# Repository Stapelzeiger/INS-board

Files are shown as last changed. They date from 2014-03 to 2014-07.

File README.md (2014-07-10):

INS-board
=========
This is a compact inertial navigation system (INS) board.
It is used as an autopilot for quad-copters and fixed wing aircrafts.

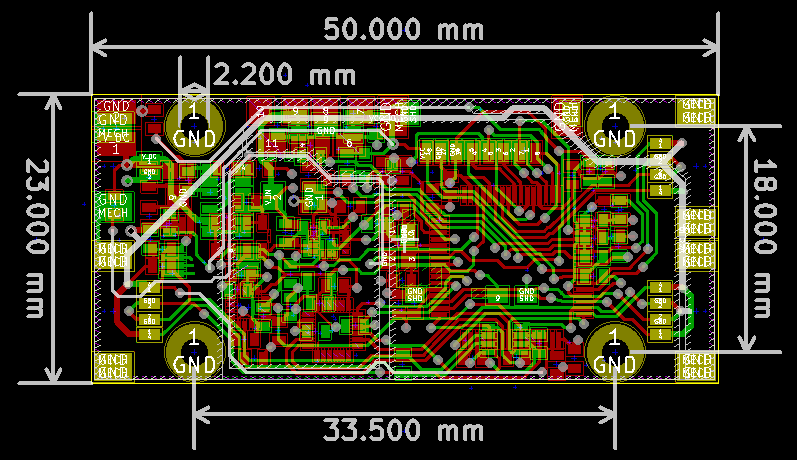
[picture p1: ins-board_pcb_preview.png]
Board Layout


Main features:
-------------
 - 3-axis gyroscope
 - Two 3-axis accelerometers (one for low g and one for high g accelerations)
 - 3-axis magnetometer
 - Barometer
 - ARM controller with FPU
 - microSD card
 - USB
 - 1x CAN
 - 4x UARTs
 - 1x I2C

Finished board
--------------

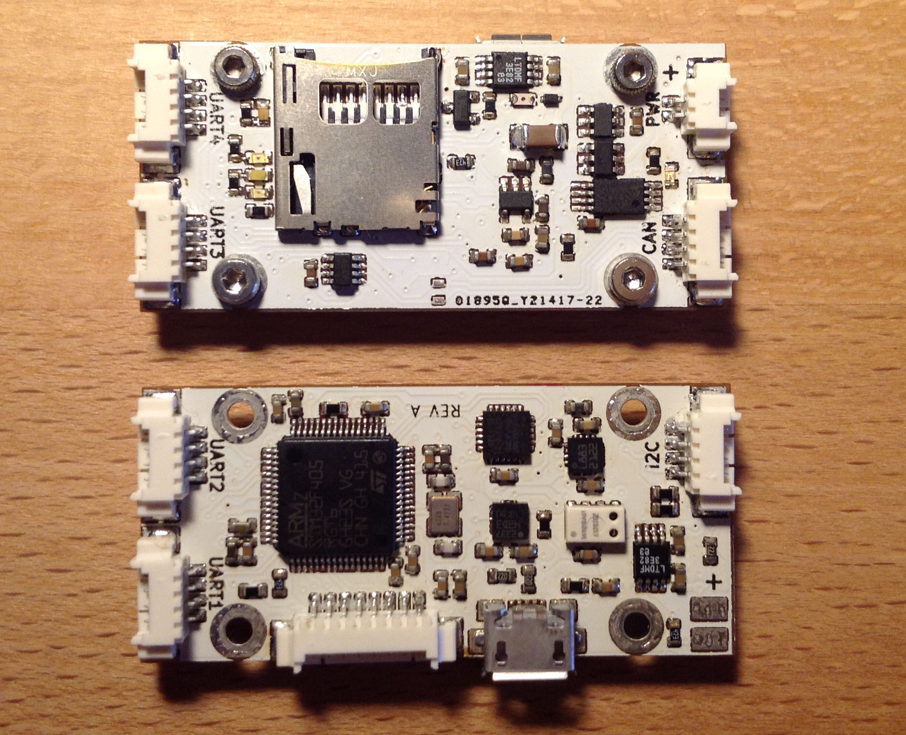
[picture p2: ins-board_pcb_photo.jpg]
Board Layout


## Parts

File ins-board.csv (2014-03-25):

Id | Designator | Package | Quantity | Designation | Supplier and ref
1 | C26 | SM1206 | 1 | 100uF
2 | X1 | _TSX-3225-SMD-XTAL | 1 | CRYSTAL 16MHz 10ppm
3 | U3 | _TSOT23-6 | 1 | LTC4412
4 | U6 | _TSOT23-5 | 1 | LT1761-3.3
5 | U4 | _SOT23-8 | 1 | MAX3051
6 | U5,U7 | _MSOP-8-EP | 2 | LT1965
7 | U8 | _MS5611-01BA | 1 | MS5611-01BA
8 | CONN3 | _Micro-USB-AB-receptacle-SMT | 1 | MICRO_USB
9 | U2 | _LQFP64 | 1 | STM32F415RGT6
10 | U10 | _HMC5883L | 1 | HMC5883L
11 | U11 | _H3LIS331DL | 1 | H3LIS331DL
12 | Q2 | _FAIRCHILD-MOSFET-SuperSOT-6 | 1 | FDC638APZ
13 | Q1 | _FAIRCHILD-MOSFET-SuperSOT-3 | 1 | FDN306P
14 | _M2,_M2,_M2,_M2 | _M2 | 4 | VAL**
15 | C6,C13,C9,C14,C10,C8,C7,C3,C28,C34,C32,C33,C29,C30,C19,C4,C17 | _0603-W | 17 | 0.1uF
16 | R21,R20,R14 | _0603-W | 3 | 47k
17 | C11,C12 | _0603-W | 2 | 2.2uF
18 | R8,R9,R7,R1,R6 | _0603-W | 5 | 1k
19 | R5,R2 | _0603-W | 2 | 10k
20 | R17,R16,R10,R11 | _0603-W | 4 | 4.7k
21 | C5,C2,C21,C27 | _0603-W | 4 | 1uF
22 | C1,C37,C18,C22,C25,C20,C23 | _0603-W | 7 | 10uF
23 | C36 | _0603-W | 1 | 4.7uF
24 | C35 | _0603-W | 1 | 0.22uF
25 | C31 | _0603-W | 1 | 2.2nF 50V
26 | R18 | _0603-W | 1 | NP / 120
27 | R12,R13 | _0603-W | 2 | 22
28 | F1 | _0603-W | 1 | FUSE 500mA
29 | R15 | _0603-W | 1 | 0
30 | R4,R3 | _0603-W | 2 | R
31 | FB1 | _0603-W | 1 | BLM18KG601SN1
32 | C24 | _0603-W | 1 | 0.01uF
33 | C15,C16 | _0603-W | 2 | 10pF
34 | D4 | _0603-W | 1 | STATUS
35 | D1 | _0603-W | 1 | SD ACT
36 | D5 | _0603-W | 1 | HEARTBEAT
37 | D3 | _0603-W | 1 | ERROR
38 | D2 | _0603-W | 1 | POWER
39 | U9 | _MPU-60X0 | 1 | MPU6000
40 | CONN2 | _Molex-microSD-502570-0893 | 1 | MICRO_SD
41 | CONN4 | _Molex-PicoBlade-SMD-4 | 1 | I2C/UART
42 | CONN5 | _Molex-PicoBlade-SMD-4 | 1 | CAN
43 | CONN6,CONN8,CONN9,CONN7 | _Molex-PicoBlade-SMD-4 | 4 | UART
44 | CONN1 | _Molex-PicoBlade-SMD-8 | 1 | JTAG
45 | P1 | _Molex-PicoBlade-SMD-2 | 1 | PWR
46 | P2 | _Solder_Pad2.54_2 | 1 | Power (Solder Pad)
47 | D6 | _SC79 | 1 | BAS52-02V
48 | U1 | _TSSOP-8 | 1 | 24LC128

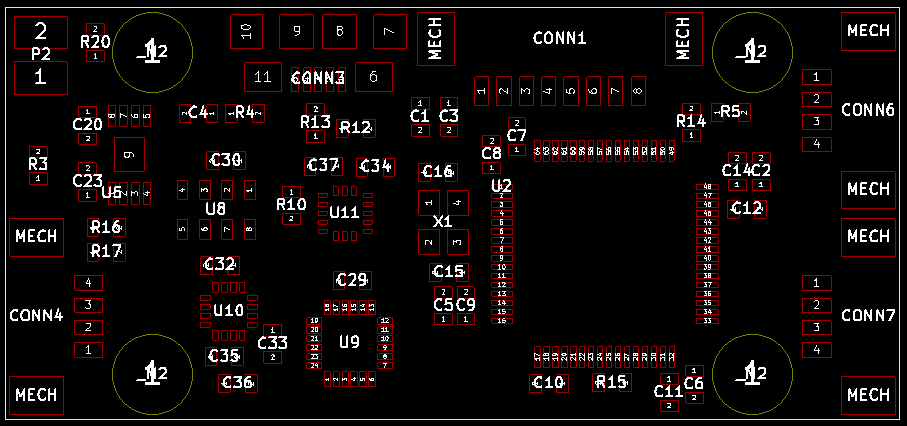
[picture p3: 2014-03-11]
ins-board-components.F.Cu.png

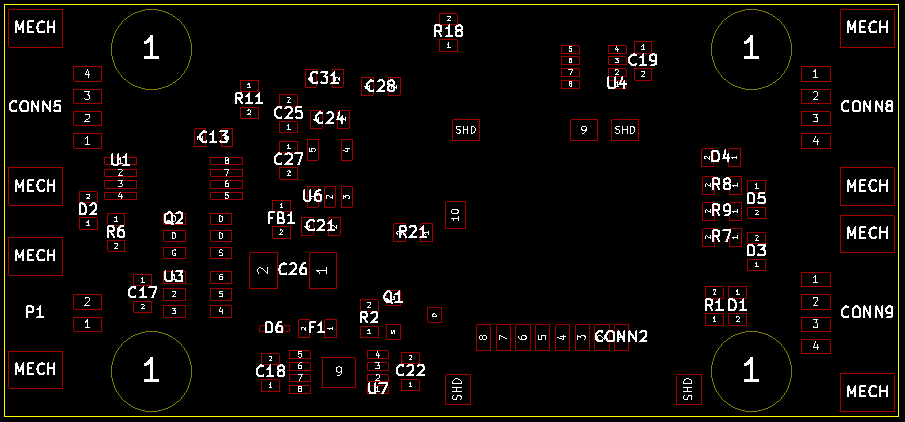
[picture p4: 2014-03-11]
ins-board-components.B.Cu.png

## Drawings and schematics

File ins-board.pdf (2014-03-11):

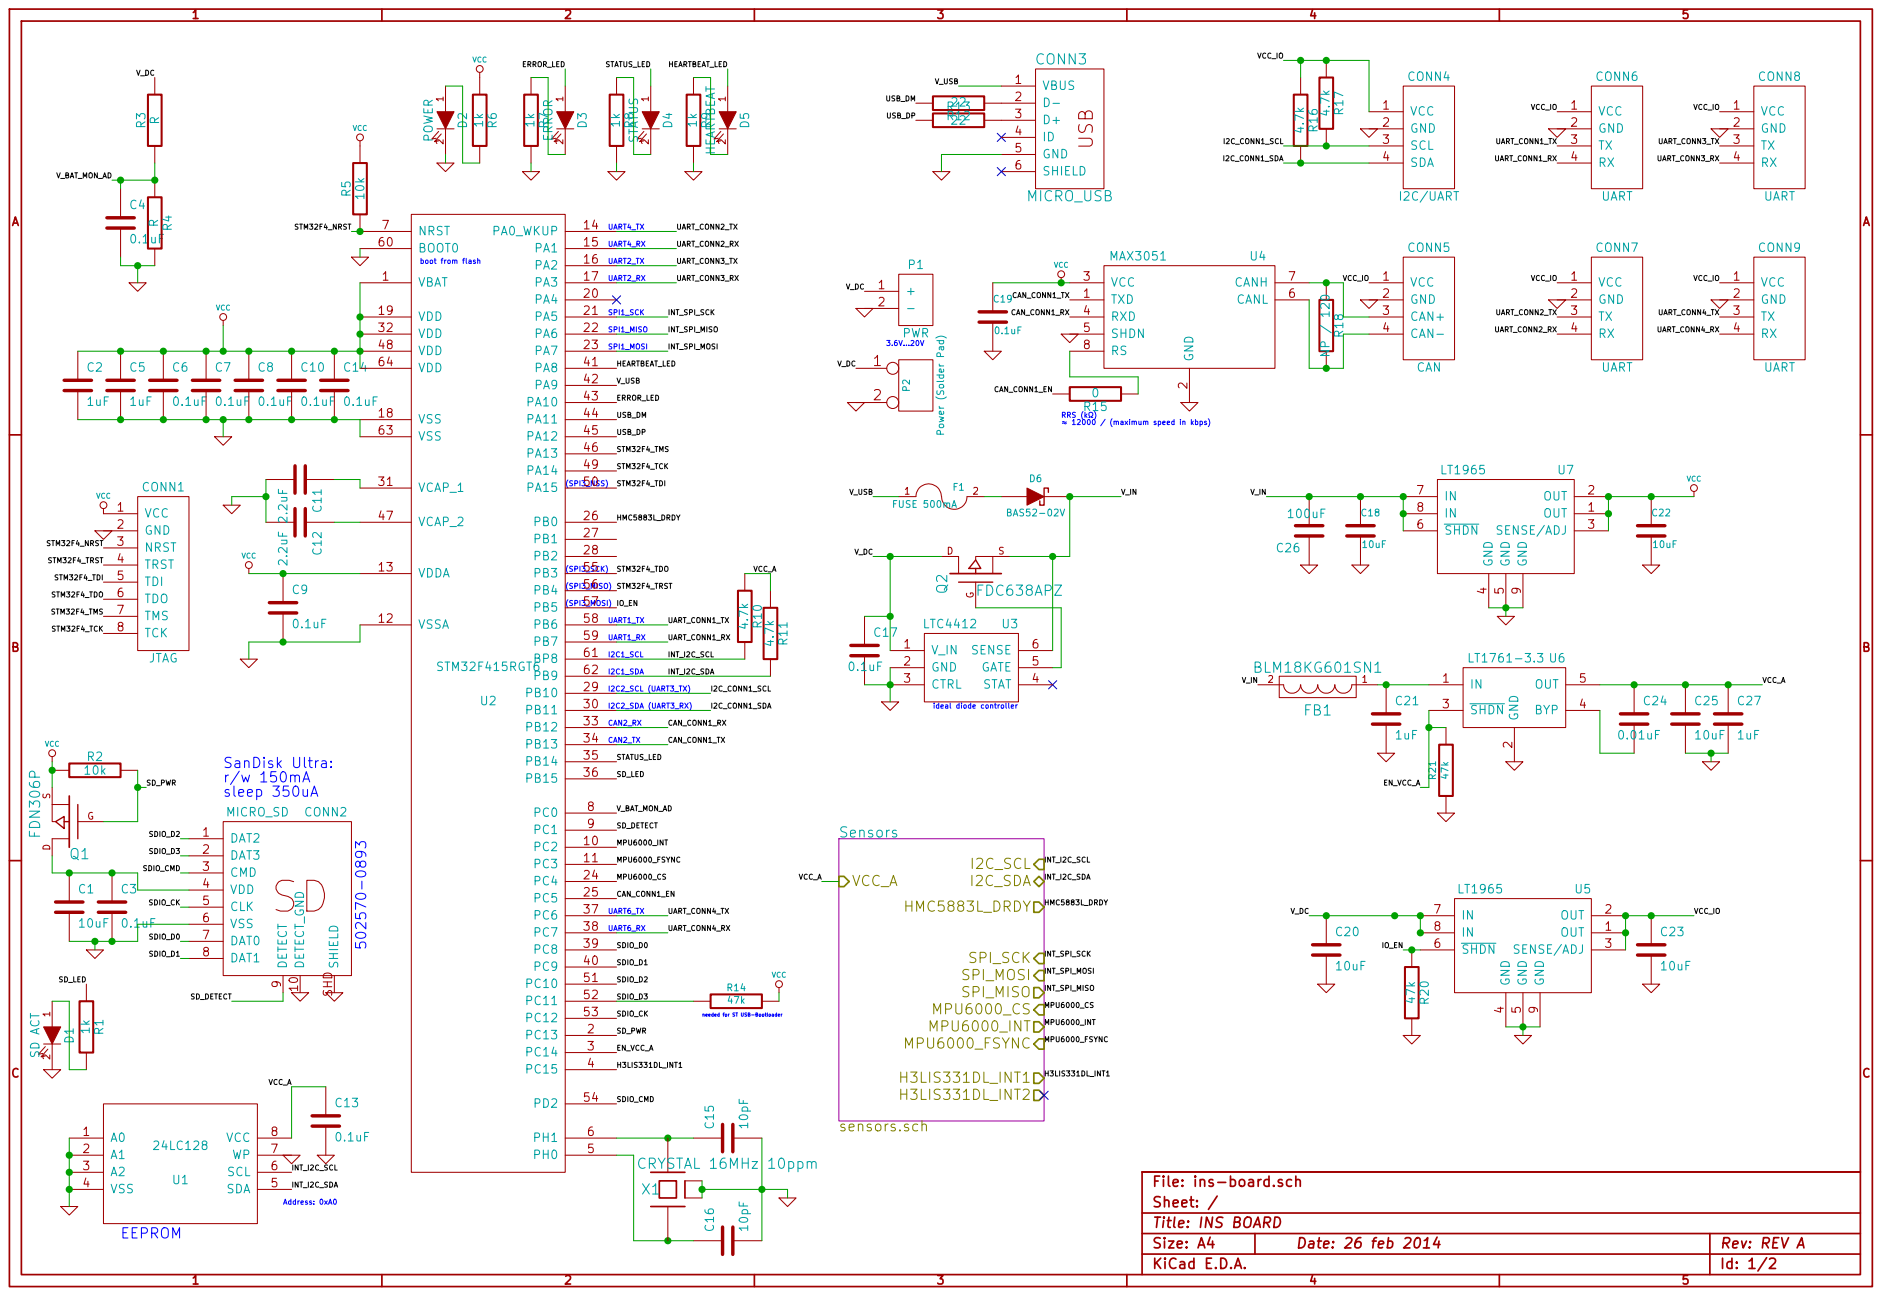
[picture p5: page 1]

boot from flash VCC R5 10k

2 VCC 3 RXD 4 SHDN 5 CANL 6 CANH 7 RS 8 MAX3051 U4

File: ins-board.sch Sheet: /

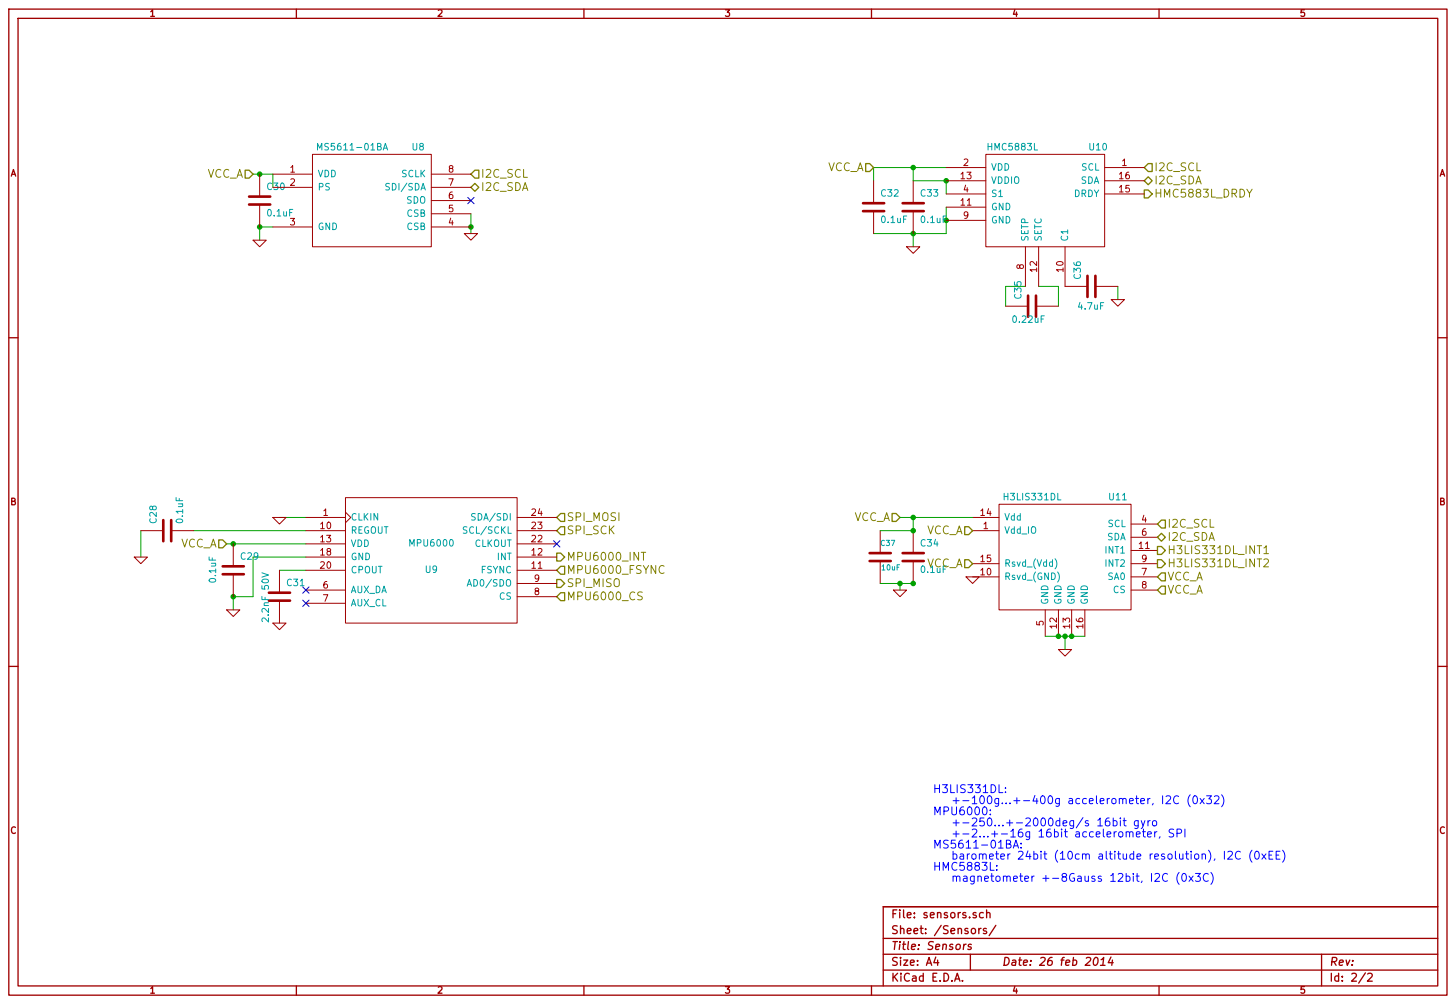
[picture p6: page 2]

8 GND 9 C1 10 GND 11 SETC 12 VDDIO 13 DRDY 15 SDA 16 HMC5883L U10 C33

Title: Sensors File: sensors.sch Sheet: /Sensors/

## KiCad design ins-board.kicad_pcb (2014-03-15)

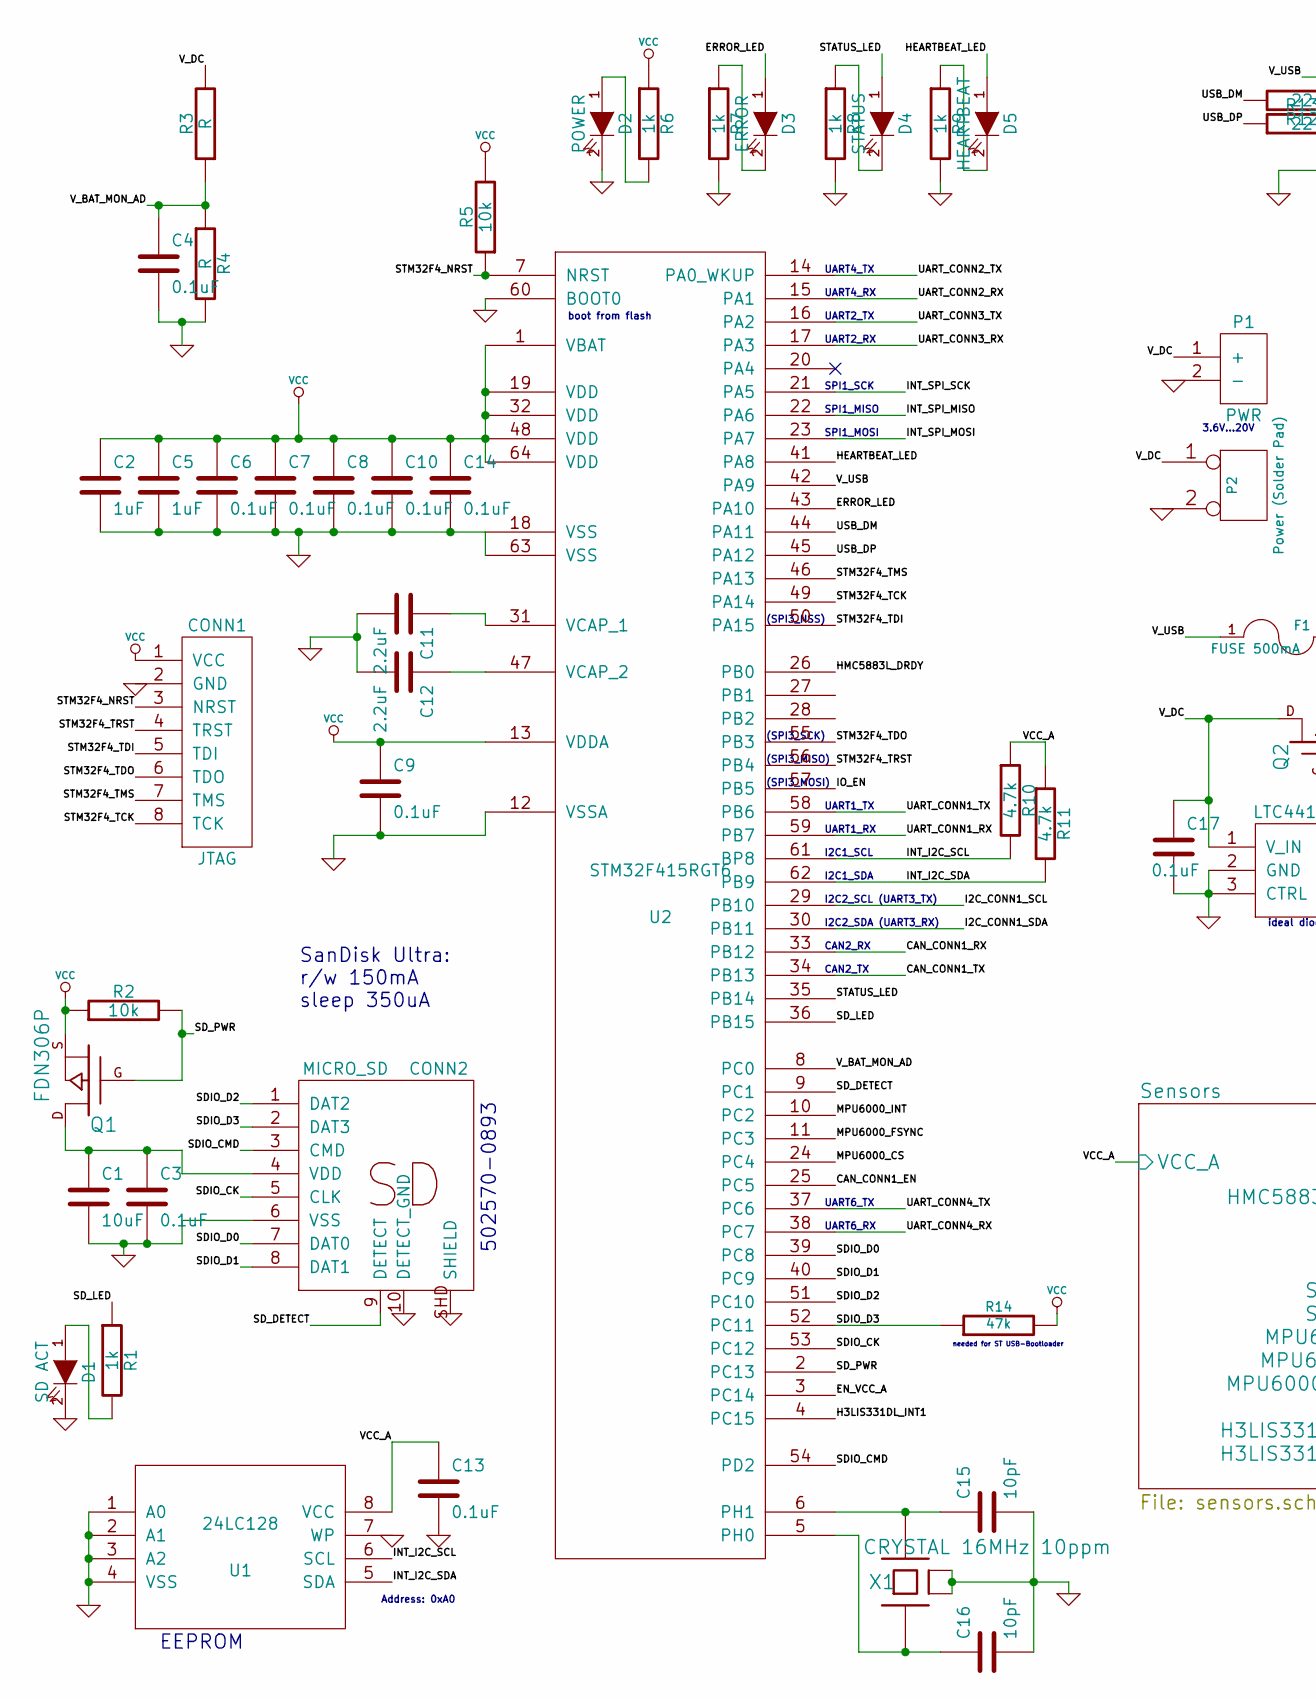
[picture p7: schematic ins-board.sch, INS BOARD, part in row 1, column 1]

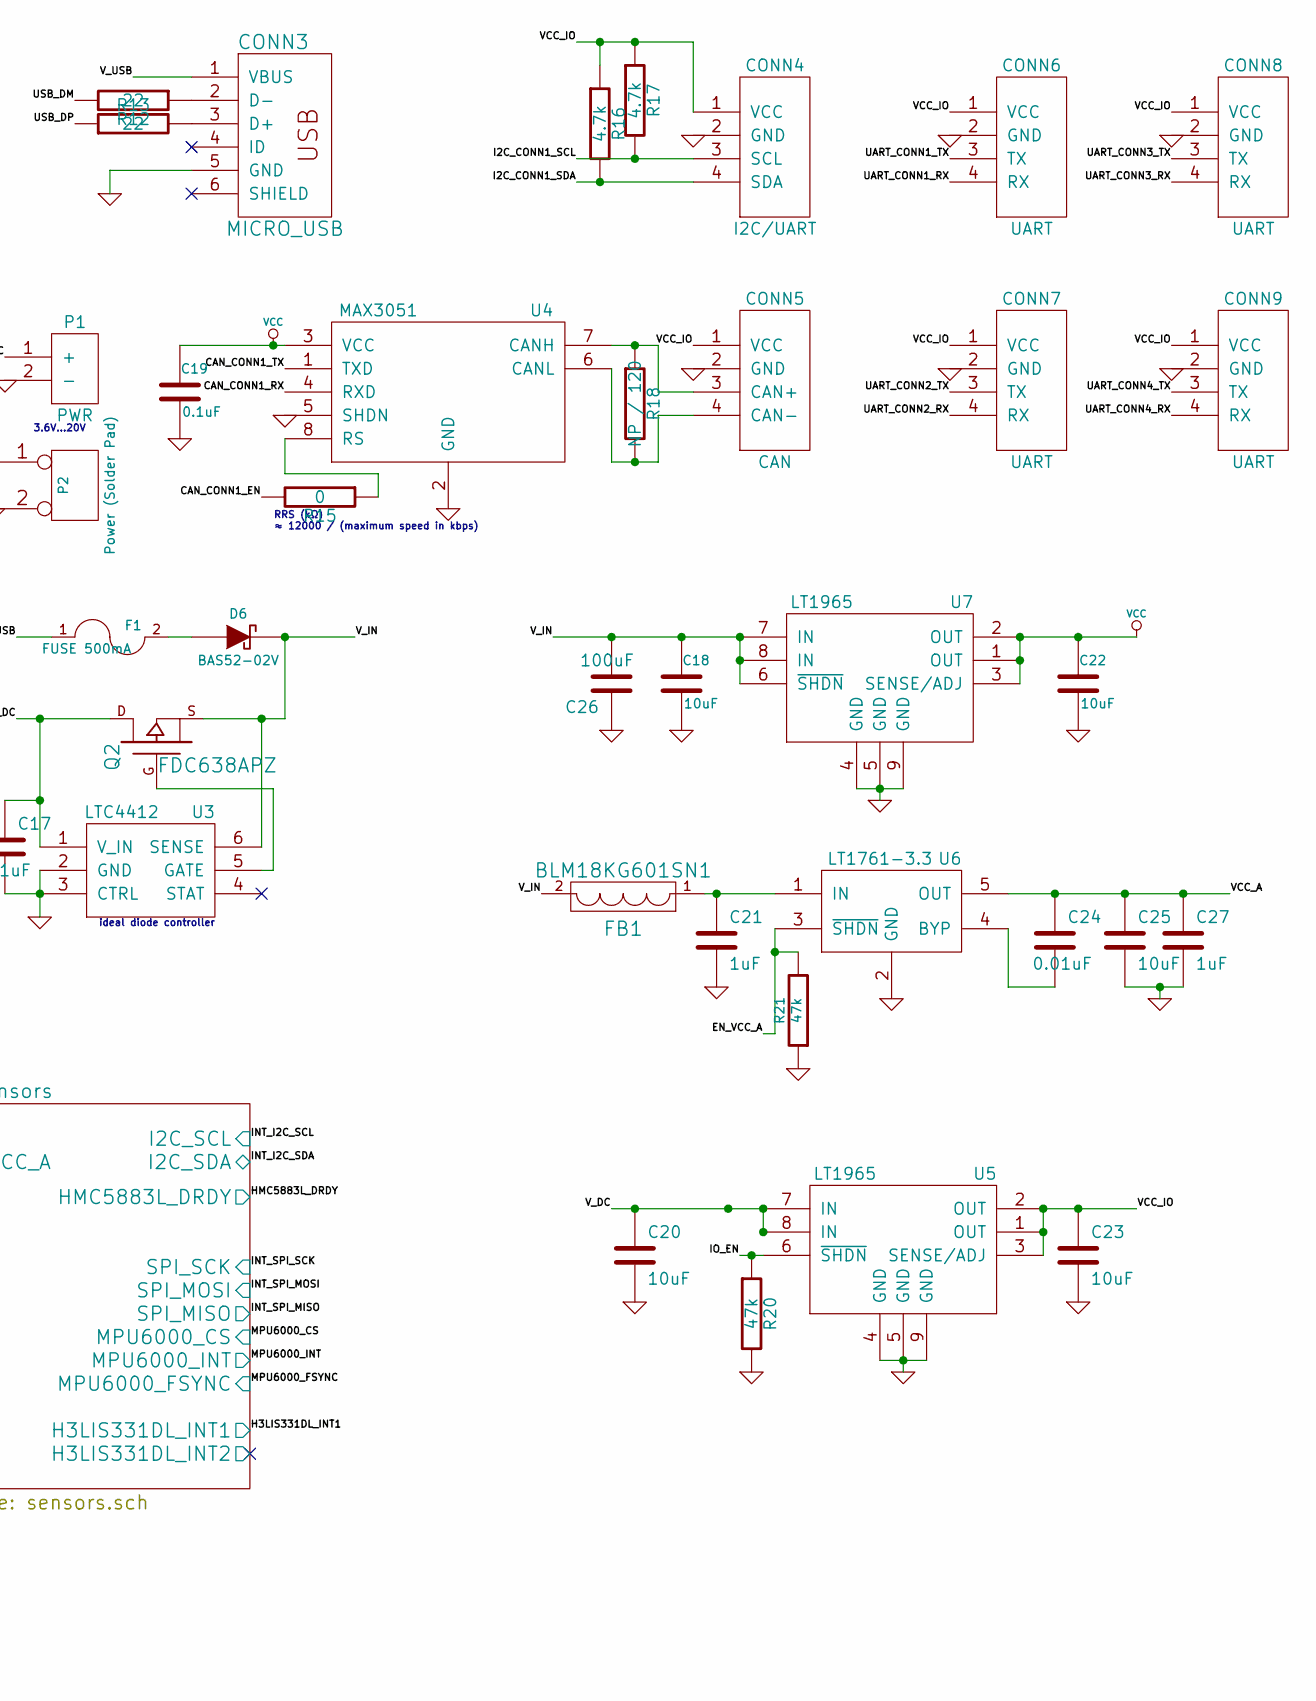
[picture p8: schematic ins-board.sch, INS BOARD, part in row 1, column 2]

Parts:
C1, C20, C23, C25: 10uF
C2, C5, C21, C27: 1uF
C3, C4, C6, C7, C8, C9, C10, C13, C14, C17: 0.1uF
C11, C12: 2.2uF
C15, C16: 10pF
C18, C22: 10uF
C19: 0.1uF
C24: 0.01uF
C26: 100uF; PartNum EMK325ABJ107MM-T
CONN1: JTAG; MODULE
CONN2: MICRO_SD; MODULE
CONN3: MICRO_USB
CONN4: I2C/UART; MODULE
CONN5: CAN; MODULE
CONN6, CONN7, CONN8, CONN9: UART; MODULE
D1: SD ACT
D2: POWER
D3: ERROR
D4: STATUS
D5: HEARTBEAT
D6: BAS52-02V
F1: FUSE 500mA
FB1: BLM18KG601SN1
P1: PWR; MODULE
P2: Power (Solder Pad)
Q1: FDN306P
Q2: FDC638APZ
R1, R6, R7, R8, R9: 1k
R2, R5: 10k
R3, R4: R
R10, R11, R16, R17: 4.7k
R12, R13: 22
R14, R21: 47k
R15: 0
R18: NP / 120
R20: 47k
U1: 24LC128; MODULE
U2: STM32F415RGT6; MODULE
U3: LTC4412; MODULE
U4: MAX3051; MODULE
U5, U7: LT1965; MODULE
U6: LT1761-3.3; MODULE
X1: CRYSTAL 16MHz 10ppm

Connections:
/CAN_CONN1_EN: R15.2, U2.25 (PC5)
/CAN_CONN1_RX: U2.33 (PB12), U4.4 (RXD)
/CAN_CONN1_TX: U2.34 (PB13), U4.1 (TXD)
/EN_VCC_A: R21.2, U2.3 (PC14), U6.3 (~SHDN)
/ERROR_LED: D3.1 (A), U2.43 (PA10)
/HEARTBEAT_LED: D5.1 (A), U2.41 (PA8)
/I2C_CONN1_SCL: CONN4.3 (SCL), R17.2, U2.29 (PB10)
/I2C_CONN1_SDA: CONN4.4 (SDA), R16.2, U2.30 (PB11)
/IO_EN: R20.1, U2.57 (PB5), U5.6 (~SHDN)
/SDIO_CK: CONN2.5 (CLK), U2.53 (PC12)
/SDIO_CMD: CONN2.3 (CMD), U2.54 (PD2)
/SDIO_D0: CONN2.7 (DAT0), U2.39 (PC8)
/SDIO_D1: CONN2.8 (DAT1), U2.40 (PC9)
/SDIO_D2: CONN2.1 (DAT2), U2.51 (PC10)
/SDIO_D3: CONN2.2 (DAT3), R14.1, U2.52 (PC11)
/SD_DETECT: CONN2.9 (DETECT), U2.9 (PC1)
/SD_LED: R1.1, U2.36 (PB15)
/SD_PWR: Q1.G, R2.2, U2.2 (PC13)
/STATUS_LED: D4.1 (A), U2.35 (PB14)
/STM32F4_NRST: CONN1.3 (NRST), R5.1, U2.7 (NRST)
/STM32F4_TCK: CONN1.8 (TCK), U2.49 (PA14)
/STM32F4_TDI: CONN1.5 (TDI), U2.50 (PA15)
/STM32F4_TDO: CONN1.6 (TDO), U2.55 (PB3)
/STM32F4_TMS: CONN1.7 (TMS), U2.46 (PA13)
/STM32F4_TRST: CONN1.4 (TRST), U2.56 (PB4)
/Sensors/H3LIS331DL_INT1: U2.4 (PC15); also elsewhere on the board
/Sensors/HMC5883L_DRDY: U2.26 (PB0); also elsewhere on the board
/Sensors/I2C_SCL: R10.2, U1.6 (SCL), U2.61 (BP8); also elsewhere on the board
/Sensors/I2C_SDA: R11.2, U1.5 (SDA), U2.62 (PB9); also elsewhere on the board
/Sensors/MPU6000_CS: U2.24 (PC4); also elsewhere on the board
/Sensors/MPU6000_FSYNC: U2.11 (PC3); also elsewhere on the board
/Sensors/MPU6000_INT: U2.10 (PC2); also elsewhere on the board
/Sensors/SPI_MISO: U2.22 (PA6); also elsewhere on the board
/Sensors/SPI_MOSI: U2.23 (PA7); also elsewhere on the board
/Sensors/SPI_SCK: U2.21 (PA5); also elsewhere on the board
/Sensors/VCC_A: C13.1, C24.1, C25.1, C27.1, R10.1, R11.1, U1.8 (VCC), U6.5 (OUT); also elsewhere on the board
/UART_CONN1_RX: CONN6.4 (RX), U2.59 (PB7)
/UART_CONN1_TX: CONN6.3 (TX), U2.58 (PB6)
/UART_CONN2_RX: CONN7.4 (RX), U2.15 (PA1)
/UART_CONN2_TX: CONN7.3 (TX), U2.14 (PA0_WKUP)
/UART_CONN3_RX: CONN8.4 (RX), U2.17 (PA3)
/UART_CONN3_TX: CONN8.3 (TX), U2.16 (PA2)
/UART_CONN4_RX: CONN9.4 (RX), U2.38 (PC7)
/UART_CONN4_TX: CONN9.3 (TX), U2.37 (PC6)
/USB_DM: R12.2, U2.44 (PA11)
/USB_DP: R13.1, U2.45 (PA12)
/VCC_IO: C23.1, CONN4.1 (VCC), CONN5.1 (VCC), CONN6.1 (VCC), CONN7.1 (VCC), CONN8.1 (VCC), CONN9.1 (VCC), R16.1, R17.1, U5.1 (OUT), U5.2 (OUT), U5.3 (SENSE/ADJ)
/V_BAT_MON_AD: C4.1, R3.1, R4.1, U2.8 (PC0)
/V_DC: C17.1, C20.1, P1.1 (+), P2.1, Q2.D, R3.2, U3.1 (V_IN), U5.7 (IN), U5.8 (IN)
/V_IN: C18.1, C26.2, D6.2 (K), FB1.2, Q2.S, U3.6 (SENSE), U7.6 (~SHDN), U7.7 (IN), U7.8 (IN)
/V_USB: CONN3.1 (VBUS), F1.1, U2.42 (PA9)
GND: C1.2, C2.2, C3.2, C4.2, C5.2, C6.2, C7.2, C8.2, C9.2, C10.2, C11.2, C12.2, C13.2, C14.2, C15.2, C16.2, C17.2, C18.2, C19.2, C20.2, C21.2, C22.2, C23.2, C25.2, C26.1, C27.2, CONN1.2 (GND), CONN1.MECH (GND), CONN2.6 (VSS), CONN2.10 (DETECT_GND), CONN2.SHD (SHIELD), CONN3.5 (GND), CONN4.2 (GND), CONN4.MECH (GND), CONN5.2 (GND), CONN5.MECH (GND), CONN6.2 (GND), CONN6.MECH (GND), CONN7.2 (GND), CONN7.MECH (GND), CONN8.2 (GND), CONN8.MECH (GND), CONN9.2 (GND), CONN9.MECH (GND), D1.2 (K), D2.2 (K), P1.2 (-), P1.MECH (GND), P2.2 (PM), R4.2, R7.2, R8.2, R9.2, R20.2, R21.1, U1.1 (A0), U1.2 (A1), U1.3 (A2), U1.4 (VSS), U1.7 (WP), U2.12 (VSSA), U2.18 (VSS), U2.60 (BOOT0), U2.63 (VSS), U3.2 (GND), U3.3 (CTRL), U4.2 (GND), U4.5 (SHDN), U5.4 (GND), U5.5 (GND), U5.9 (GND), U6.2 (GND), U7.4 (GND), U7.5 (GND), U7.9 (GND), X1.2 (case), X1.4 (case); also elsewhere on the board
unnamed: D6.1 (A), F1.2
unnamed: C24.2, U6.4 (BYP)
unnamed: R15.1, U4.8 (RS)
unnamed: C11.1, U2.31 (VCAP_1)
unnamed: C12.1, U2.47 (VCAP_2)
unnamed: D2.1 (A), R6.2
unnamed: D5.2 (K), R9.1
unnamed: D4.2 (K), R8.1
unnamed: CONN3.2 (D-), R12.1
unnamed: CONN3.3 (D+), R13.2
unnamed: C16.1, U2.5 (PH0), X1.1
unnamed: C15.1, U2.6 (PH1), X1.3
unnamed: D3.2 (K), R7.1
unnamed: Q2.G, U3.5 (GATE)
unnamed: D1.1 (A), R1.2
unnamed: C21.1, FB1.1, U6.1 (IN)
unnamed: CONN5.3 (CAN+), R18.1, U4.7 (CANH)
unnamed: CONN5.4 (CAN-), R18.2, U4.6 (CANL)
unnamed: C1.1, C3.1, CONN2.4 (VDD), Q1.D
VCC: C2.1, C5.1, C6.1, C7.1, C8.1, C9.1, C10.1, C14.1, C19.1, C22.1, CONN1.1 (VCC), Q1.S, R2.1, R5.2, R6.1, R14.2, U2.1 (VBAT), U2.13 (VDDA), U2.19 (VDD), U2.32 (VDD), U2.48 (VDD), U2.64 (VDD), U4.3 (VCC), U7.1 (OUT), U7.2 (OUT), U7.3 (SENSE/ADJ)

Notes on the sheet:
ideal diode controller
Address: 0xA0
SanDisk Ultra: r/w 150mA sleep 350uA
(SPI3_MOSI)
(SPI3_MISO)
(SPI3_SCK)
(SPI3_NSS)
CAN2_TX
CAN2_RX
I2C2_SDA (UART3_RX)
I2C2_SCL (UART3_TX)
I2C1_SDA
I2C1_SCL
UART1_TX
UART1_RX
SPI1_MOSI
SPI1_MISO
SPI1_SCK
UART2_RX
UART2_TX
UART4_RX
UART4_TX
UART6_RX
UART6_TX
3.6V...20V
boot from flash
502570-0893
RRS (kΩ) ≈ 12000 / (maximum speed in kbps)
EEPROM
needed for ST USB-Bootloader

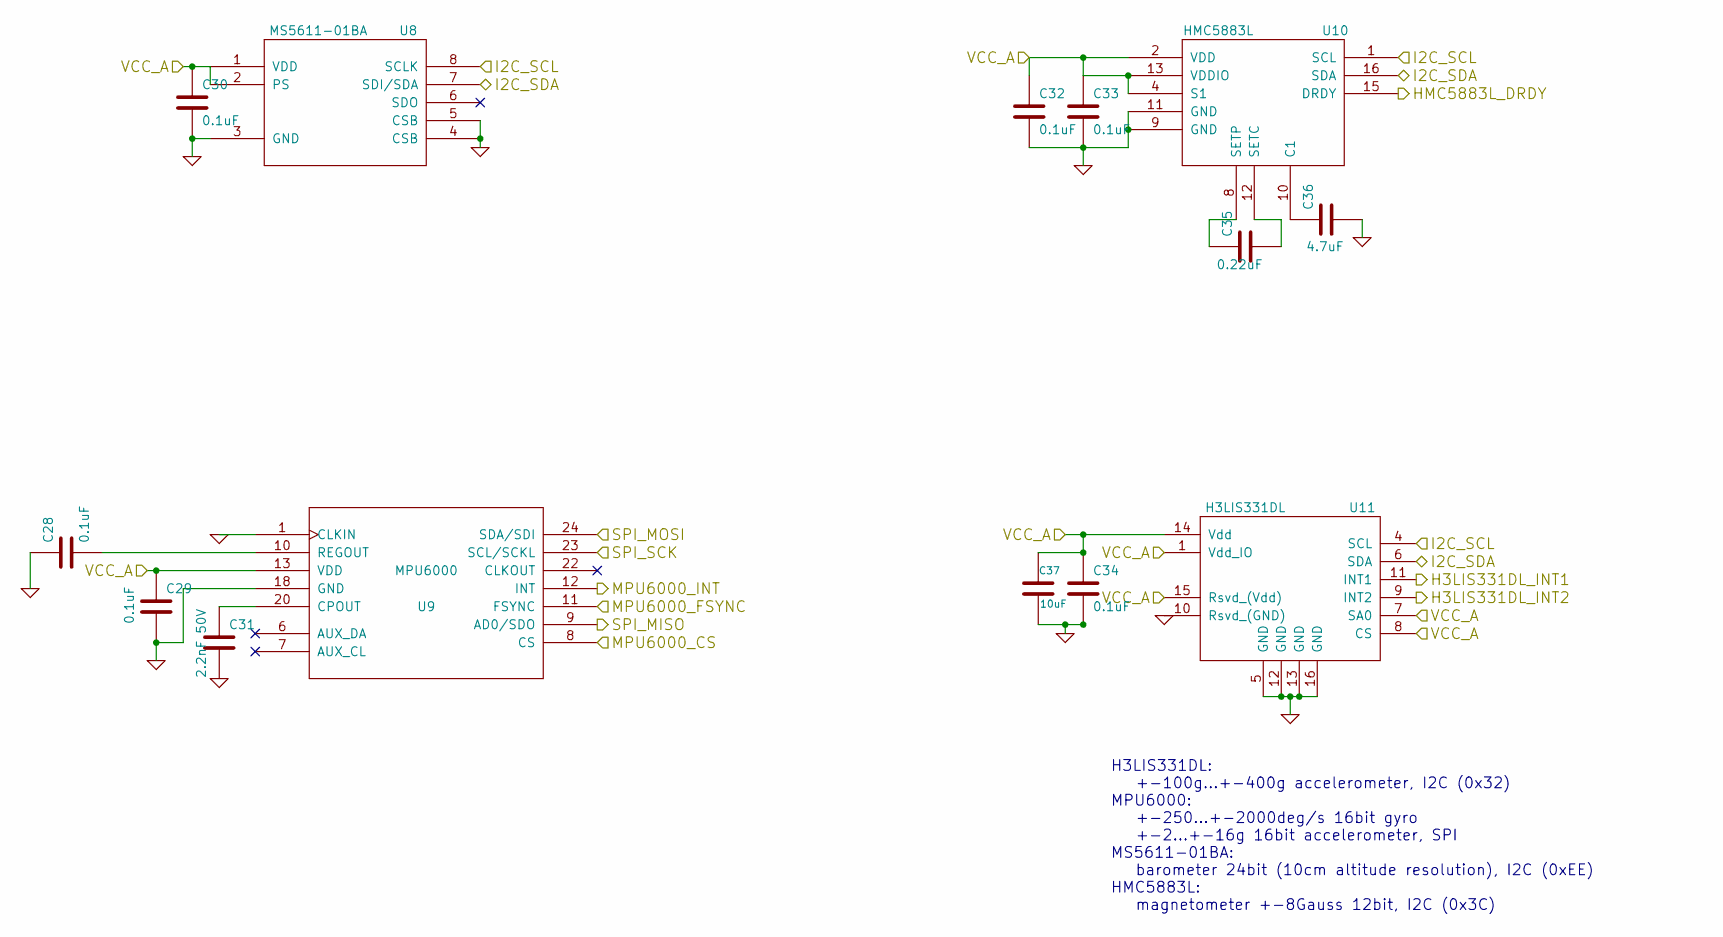
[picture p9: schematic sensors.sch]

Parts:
C28, C29, C30, C32, C33, C34: 0.1uF
C31: 2.2nF 50V
C35: 0.22uF
C36: 4.7uF
C37: 10uF
U8: MS5611-01BA; MODULE
U9: MPU6000; MODULE
U10: HMC5883L; MODULE
U11: H3LIS331DL; MODULE

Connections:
/Sensors/H3LIS331DL_INT1: U11.11 (INT1); also elsewhere on the board
/Sensors/HMC5883L_DRDY: U10.15 (DRDY); also elsewhere on the board
/Sensors/I2C_SCL: U8.8 (SCLK), U10.1 (SCL), U11.4 (SCL); also elsewhere on the board
/Sensors/I2C_SDA: U8.7 (SDI/SDA), U10.16 (SDA), U11.6 (SDA); also elsewhere on the board
/Sensors/MPU6000_CS: U9.8 (CS); also elsewhere on the board
/Sensors/MPU6000_FSYNC: U9.11 (FSYNC); also elsewhere on the board
/Sensors/MPU6000_INT: U9.12 (INT); also elsewhere on the board
/Sensors/SPI_MISO: U9.9 (AD0/SDO); also elsewhere on the board
/Sensors/SPI_MOSI: U9.24 (SDA/SDI); also elsewhere on the board
/Sensors/SPI_SCK: U9.23 (SCL/SCKL); also elsewhere on the board
/Sensors/VCC_A: C29.1, C30.1, C32.1, C33.1, C34.1, C37.1, U8.1 (VDD), U8.2 (PS), U9.13 (VDD), U10.2 (VDD), U10.4 (S1), U10.13 (VDDIO), U11.1 (Vdd_IO), U11.7 (SA0), U11.8 (CS), U11.14 (Vdd), U11.15 (Rsvd_(Vdd)); also elsewhere on the board
GND: C28.1, C29.2, C30.2, C31.2, C32.2, C33.2, C34.2, C36.2, C37.2, U8.3 (GND), U8.4 (CSB), U8.5 (CSB), U9.1 (CLKIN), U9.18 (GND), U10.9 (GND), U10.11 (GND), U11.5 (GND), U11.10 (Rsvd_(GND)), U11.12 (GND), U11.13 (GND), U11.16 (GND); also elsewhere on the board
unnamed: C35.1, U10.8 (SETP)
unnamed: C36.1, U10.10 (C1)
unnamed: C35.2, U10.12 (SETC)
unnamed: C31.1, U9.20 (CPOUT)
unnamed: C28.2, U9.10 (REGOUT)

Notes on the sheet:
H3LIS331DL: +-100g...+-400g accelerometer, I2C (0x32) MPU6000: +-250...+-2000deg/s 16bit gyro +-2...+-16g 16bit accelerometer, SPI MS5611-01BA: barometer 24bit (10cm altitude resolution), I2C (0xEE) HMC5883L: magnetometer +-8Gauss 12bit, I2C (0x3C)

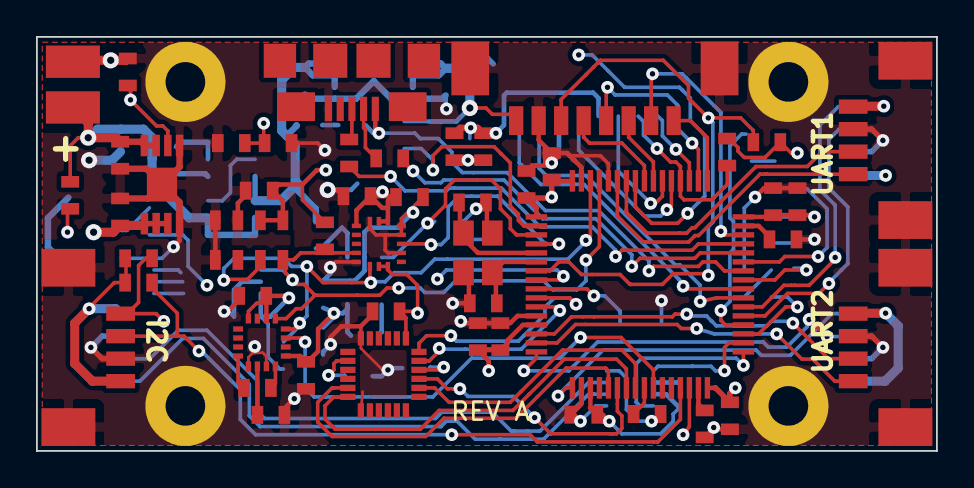
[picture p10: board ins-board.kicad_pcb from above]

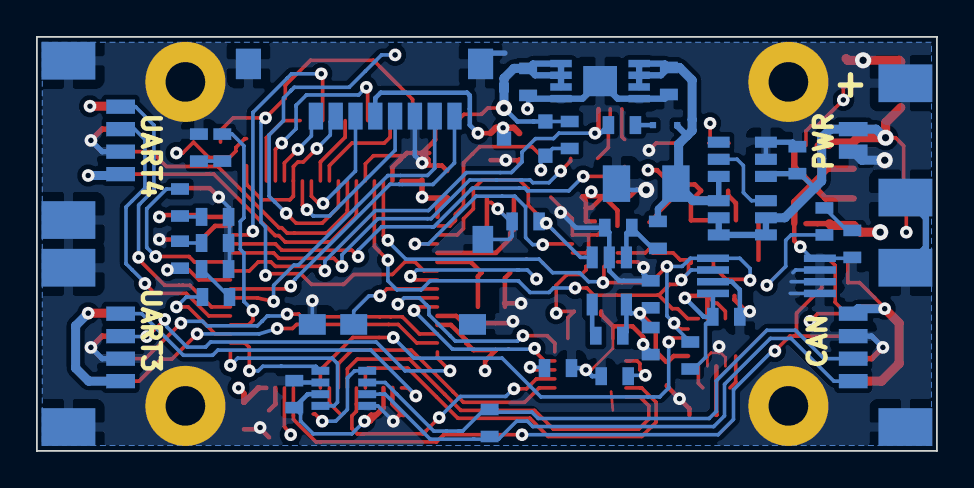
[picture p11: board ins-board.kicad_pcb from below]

Board: 4 copper layers, 50.0 x 23.0 mm, 94 parts (41 on the bottom side), 77 nets.

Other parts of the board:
_M2, _M2#2, _M2#3, _M2#4: VAL**; _M2

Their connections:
GND: _M2.1, _M2#2.1, _M2#3.1, _M2#4.1; also elsewhere on the board

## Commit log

2014-02-03 added a KiCad library submodule
2014-02-03 updated kicad-library
2014-02-03 updated kicad-lib
2014-02-03 add mosfet for current limiter
    [ins-board.sch]
2014-02-06 remove usb shield connection
    [ins-board.sch, sensors.sch]
2014-02-07 fix errors detected by ERC
    [ins-board.sch, sensors.sch]
2014-02-07 replaced crystal symbol
    [ins-board.sch, sensors.sch]
2014-02-07 assigned most footprints to symbols
    added missing footprint library references to project file.
2014-02-07 changed shunt resistor to 68mOhm, 0603
    [ins-board.sch, sensors.sch]
2014-02-07 switched to renamed component and footprint libraries
    [ins-board.sch, sensors.sch]
2014-02-09 new power design
    - separate voltage regulator for io-connectors (powered from DC-in only)
    - removed io hot-swap controller
    [ins-board.sch, sensors.sch]
2014-02-09 updated annotation, added MOSFET footprints
    [ins-board.sch, sensors.sch]
2014-02-10 updated crystal load capacitor values
    [ins-board.sch]
2014-02-11 updated some capacitor footprints
    [ins-board.sch, sensors.sch]
2014-02-11 added capacitor for max3051
    [ins-board.sch]
2014-02-13 changed sensors power supply (VCC_IO = VCC_A)
    - all sensors and the eeprom are now powered by VCC_A
    - internal I2C pullups to VCC_A
    Reason: MS5611-01BA, HMC5883L datasheets don't specify behaviour if only vcc_io is powered / if I2C is pulled to VCC while chip is powered down
    [ins-board.sch, sensors.sch]
2014-02-13 corrected connection error
    U5 pin 8,6 were connected
    [ins-board.sch]
2014-02-13 sort components
    [ins-board.kicad_pcb]
2014-02-13 change 24LC128 footprint from TSSOP to MSOP
    reason: smaller
    [ins-board.kicad_pcb]
2014-02-13 add m2 mounting holes
    [ins-board.kicad_pcb]
2014-02-14 changed SD card holder + some minor power supply changes
    [ins-board.sch, sensors.sch]
2014-02-14 layout
    90% of components
    [ins-board.kicad_pcb]
2014-02-15 add sd-card adapter, change 0603 footprints, design rules
    [ins-board.kicad_pcb]
2014-02-15 started routing
    [ins-board.kicad_pcb]
2014-02-16 updated library, changed component names according to new lib
    This fixes the library editor problem, where components disappear.
    [ins-board.sch, sensors.sch]
2014-02-16 modified sd card symbol to match footprint
    [ins-board.sch, sensors.sch]
2014-02-17 signal routing
    [ins-board.kicad_pcb]
2014-02-18 signal routing, all components placed
    [ins-board.kicad_pcb, ins-board.sch]
2014-02-18 solid copper connection for mounting holes
    [ins-board.kicad_pcb]
2014-02-19 power routing
    [ins-board.kicad_pcb]
2014-02-21 routing, added dimensions
    [ins-board.kicad_pcb]
2014-02-22 routing (io_en)
    [ins-board.kicad_pcb, ins-board.sch, sensors.sch]
2014-02-24 power supply solder pad connector
    [ins-board.kicad_pcb, ins-board.sch, sensors.sch]
2014-02-25 routing 100%
    [ins-board.kicad_pcb]
2014-02-25 optimize routing
    [ins-board.kicad_pcb]
2014-02-25 small fix, passes drc (except pad-to-pad distance for footprints)
    [ins-board.kicad_pcb]
2014-02-25 connect molex mechanical connector pads to GND
    [ins-board.kicad_pcb, ins-board.sch, sensors.sch]
2014-02-26 keepout zones for sd card holder in gnd-fill
    [ins-board.kicad_pcb]
2014-02-26 add V_USB diode with correct footprint
    [ins-board.kicad_pcb, ins-board.sch, sensors.sch]
2014-02-27 optimize zones
    [ins-board.kicad_pcb]
2014-02-28 replaced silkscreen with simple connector labels
    [ins-board.kicad_pcb]
2014-03-02 better GND connection of EEPROM capacitor
    [ins-board.kicad_pcb]
2014-03-05 changed eeprom package from MSOP to TSSOP
    [ins-board.kicad_pcb]
2014-03-07 center / resize all references & values
    [ins-board.kicad_pcb]
2014-03-07 added missing GND track for eeprom
    [ins-board.kicad_pcb]
2014-03-15 add REV A to pcb
    [ins-board.kicad_pcb]
2014-03-17 created gerber and drill output files
    [ins-board-B_Cu.gbl, ins-board-B_SilkS.gbo, ins-board-Edge_Cuts.gbr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]
2014-03-17 added soldermask layers in gerber
    [ins-board-B_Cu.gbl, ins-board-B_Mask.gbs, ins-board-B_SilkS.gbo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]
2014-03-25 add BOM
    [ins-board.csv]
